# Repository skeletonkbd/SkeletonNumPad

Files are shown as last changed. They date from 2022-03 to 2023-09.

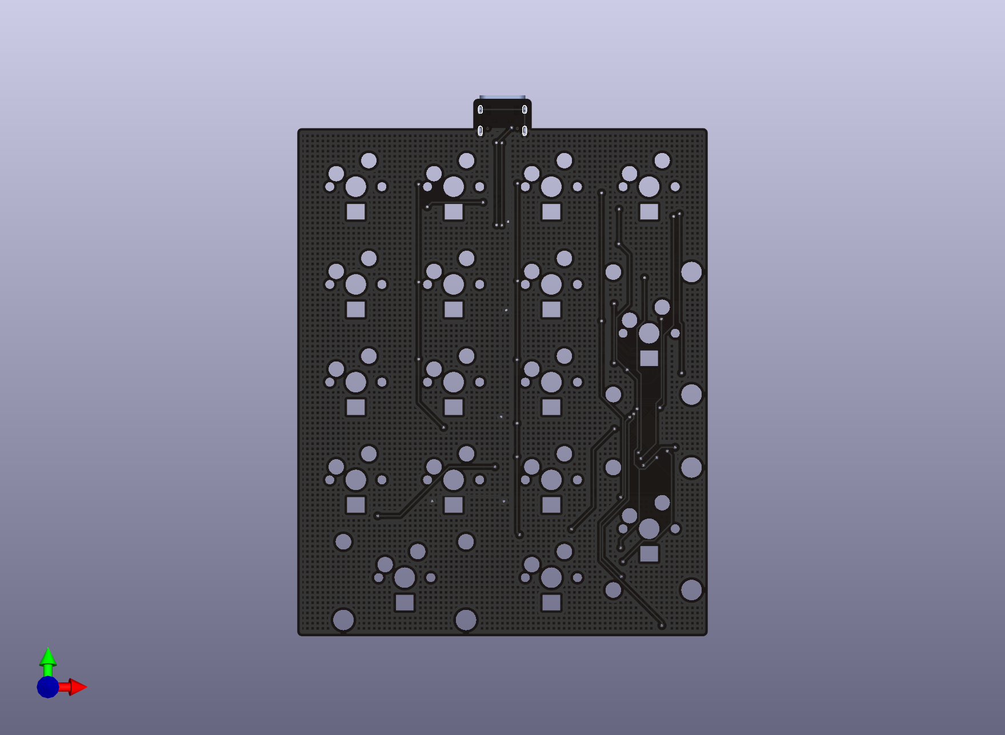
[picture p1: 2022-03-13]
3d/front.png

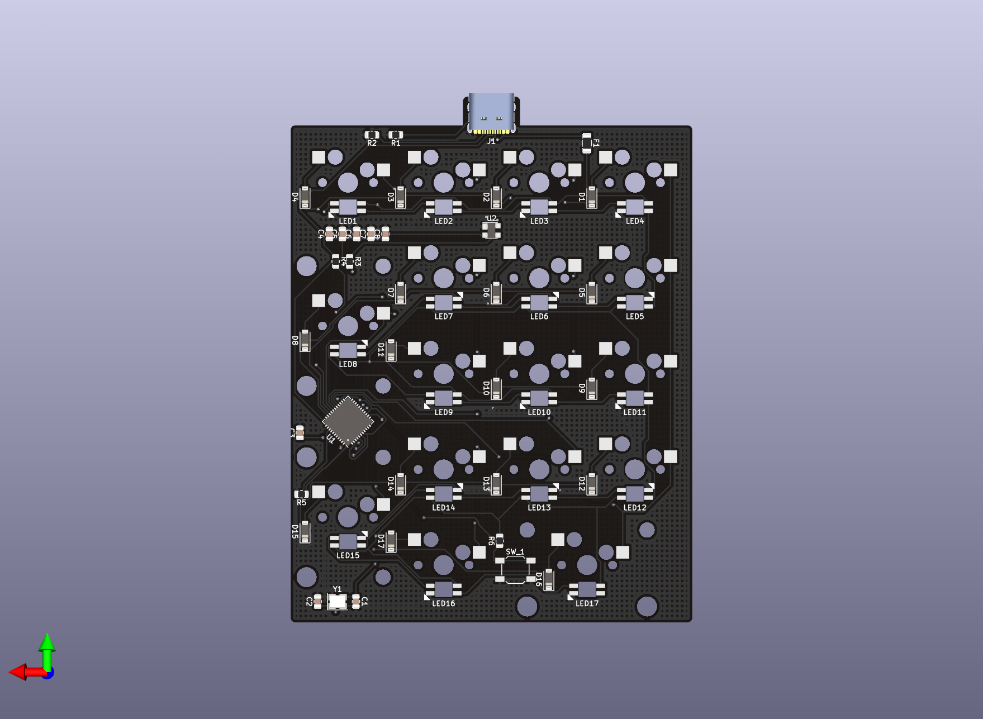
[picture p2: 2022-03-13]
3d/bottom.png

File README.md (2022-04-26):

# SkeletonNumPad

シンプルなNumpadです。販売ページは[こちら](https://skeletonkbd.com/products/numpad)。

## 特徴
- アクリル積層ケース
- バックライトLED
- ホットスワップ

# 組み立て例

skeletonNumPad

skeletonNumPad2

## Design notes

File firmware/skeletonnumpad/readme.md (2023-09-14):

# SkeletonNumPad

skeletonnumpad

Simple NumPad with acrylic case.

-   Keyboard Maintainer: [SkeletonKBD](https://github.com/skeletonkbd/SkeletonNumPad)
-   Hardware Supported: SkeletonNumPad
-   Hardware Availability: https://github.com/skeletonkbd/SkeletonNumPad

Make example for this keyboard (after setting up your build environment):

    make skeletonkbd/skeletonnumpad:default

Flashing example for this keyboard:

    make skeletonkbd/skeletonnumpad:default:flash

See the [build environment setup](https://docs.qmk.fm/#/getting_started_build_tools) and the [make instructions](https://docs.qmk.fm/#/getting_started_make_guide) for more information. Brand new to QMK? Start with our [Complete Newbs Guide](https://docs.qmk.fm/#/newbs).

## Bootloader

Enter the bootloader in 3 ways:

-   **Bootmagic reset**: Hold down the key at (0,0) in the matrix (usually the top left key or Escape) and plug in the keyboard
-   **Physical reset button**: Briefly press the button on the back of the PCB - some may have pads you must short instead
-   **Keycode in layout**: Press the key mapped to `QK_BOOT` if it is available

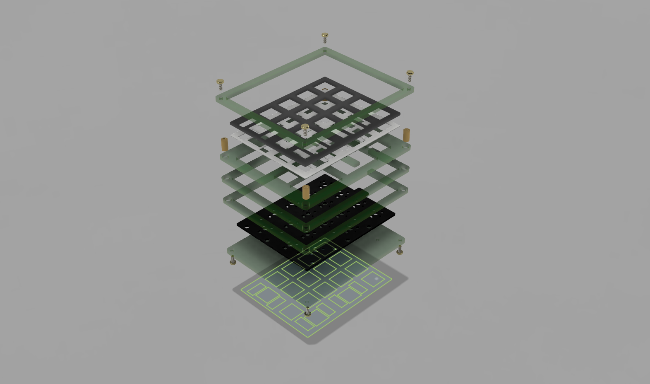
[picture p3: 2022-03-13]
3d/shape/SkeletonNumPad v3.png

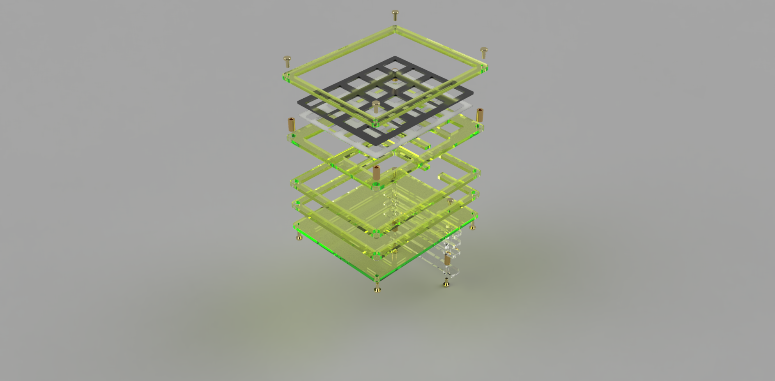
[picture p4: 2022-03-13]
3d/shape/331e11d3-f67b-4a33-b418-c3e450e3e0f4.PNG

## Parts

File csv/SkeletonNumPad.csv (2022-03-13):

Comment | Designator | Footprint | LCSC
22p | C1,C2 | Capacitor_SMD:C_0805_2012Metric | C1804
1u | C3 | Capacitor_SMD:C_0805_2012Metric | C28323
0.1u | C4,C5,C6,C7 | Capacitor_SMD:C_0805_2012Metric | C49678
10u | C8 | Capacitor_SMD:C_0805_2012Metric | C15850
D_Small | D1,D2,D3,D4,D5,D6,D7,D8,D9,D10,D11,D12,D13,D14,D15,D16,D17 | Diode_SMD:D_SOD-123 | C81598
500mA | F1 | Fuse:Fuse_1206_3216Metric | C70069
USB_C_Receptacle_USB2.0 | J1 | Connector_USB:USB_C_Receptacle_Palconn_UTC16-G | C167321
YS-SK6812MINI-E | LED1,LED2,LED3,LED4,LED5,LED6,LED7,LED8,LED9,LED10,LED11,LED12,LED13,LED14,LED15,LED16,LED17 | Custom:YS-SK6812MINI-E
5.1k | R1,R2 | Resistor_SMD:R_0805_2012Metric | C27834
22 | R3,R4 | Resistor_SMD:R_0805_2012Metric | C17561
10k | R5,R6 | Resistor_SMD:R_0805_2012Metric | C17414
SW_PUSH | SW1,SW2,SW3,SW4,SW5,SW6,SW7,SW9,SW10,SW11,SW12,SW13,SW14,SW17 | Custom:MXOnly-1U-Hotswap | C2803348
SW_PUSH | SW16 | Custom:MXOnly-2U-Hotswap | C2803348
SW_PUSH | SW8,SW15 | Custom:MXOnly-2U-Hotswap-VerticalStabilizers | C2803348
SW_PUSH | SW_1 | Button_Switch_SMD:SW_SPST_SKQG_WithStem | C455263
ATmega32U4-M | U1 | Package_DFN_QFN:QFN-44-1EP_7x7mm_P0.5mm_EP5.2x5.2mm | C112161
PRTR5V0U2X | U2 | Package_TO_SOT_SMD:SOT-143 | C2827688
Crystal_GND24 | Y1 | Crystal:Crystal_SMD_3225-4Pin_3.2x2.5mm | C13738

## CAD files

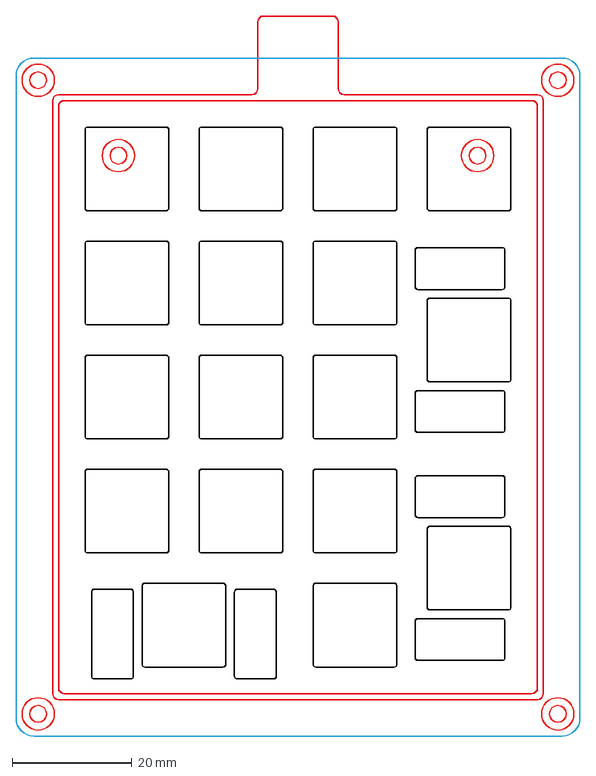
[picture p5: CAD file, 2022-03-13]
3d/shape/bottom.dxf
94.2 x 120.3 mm

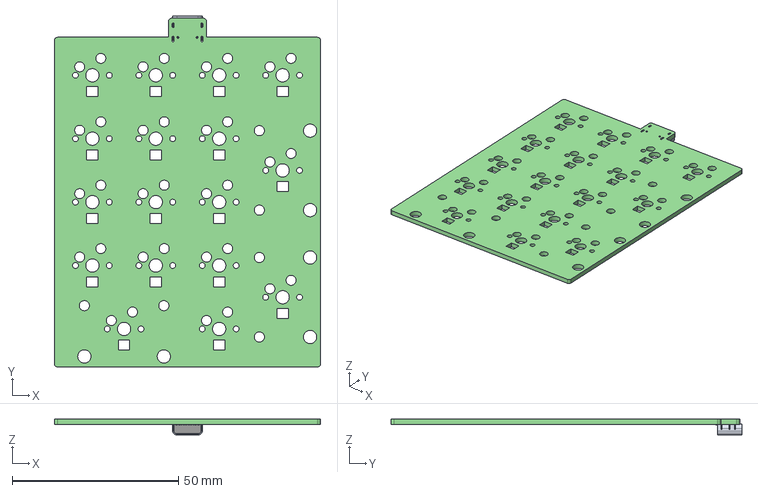
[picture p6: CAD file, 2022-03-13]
3d/SkeletonNumPad.step
80.0 x 105.4 x 4.76 mm
_autosave-SkeletonNumPad PCB

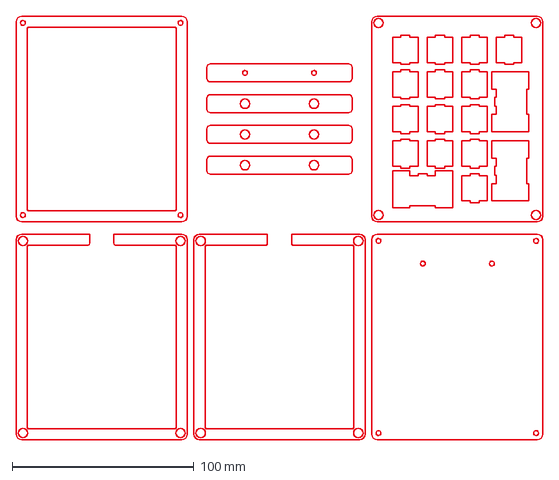
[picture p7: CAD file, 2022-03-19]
case/order-elecrow.dxf
290.0 x 233.3 mm

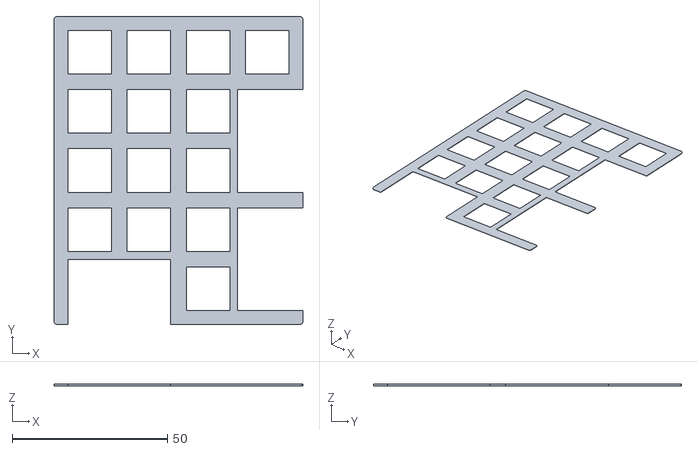
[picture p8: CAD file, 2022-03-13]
case/plate/dumper.stl
80.0 x 99.1 x 0.5

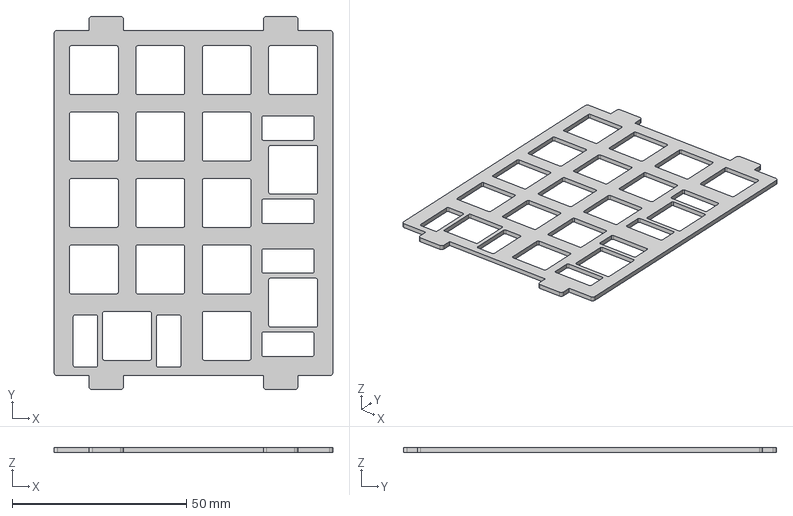
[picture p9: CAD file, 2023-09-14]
plate/SkeletonNumPad_plate.step
80.0 x 107.1 x 1.50 mm

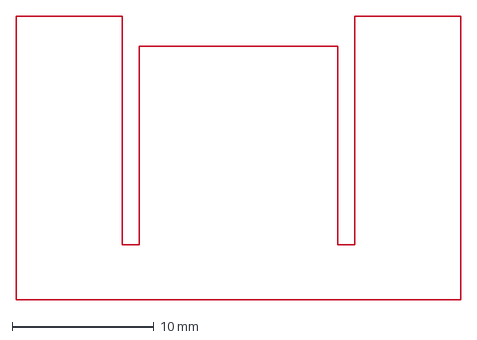
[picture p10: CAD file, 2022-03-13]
case/hole-sample.dxf
31.4 x 20.0 mm

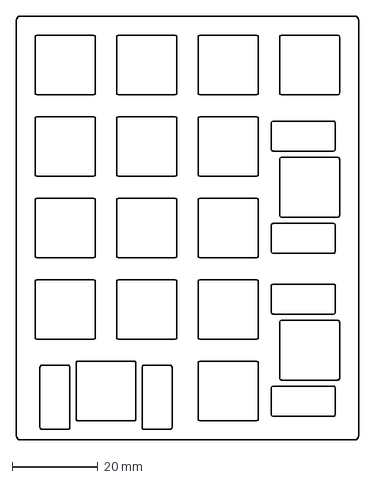
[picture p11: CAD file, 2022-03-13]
case/plate/switch-plate.dxf
80.0 x 99.1 mm

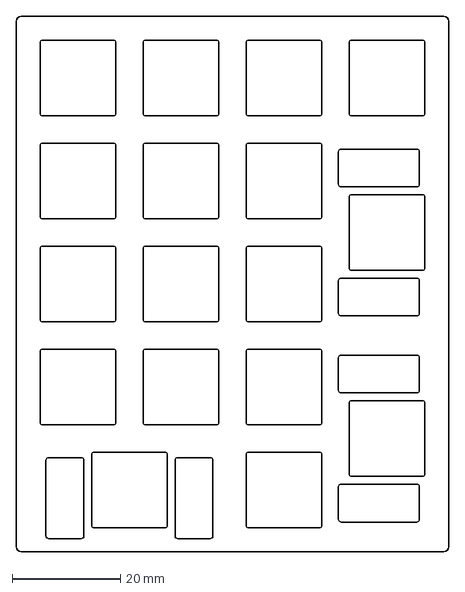
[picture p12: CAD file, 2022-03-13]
plate/switch-plate.dxf
80.0 x 99.1 mm

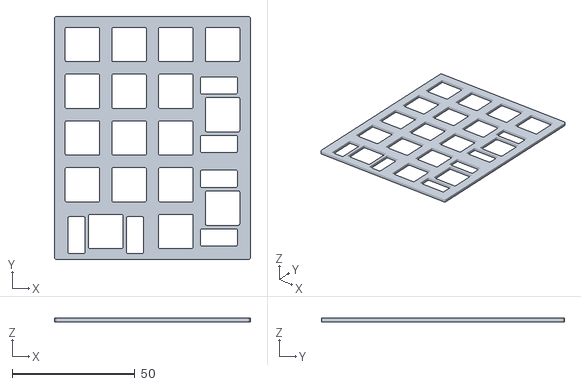
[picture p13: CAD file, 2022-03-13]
case/plate/switch-plate v1.stl
80.0 x 99.1 x 1.50

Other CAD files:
case/plate/dumper.dxf

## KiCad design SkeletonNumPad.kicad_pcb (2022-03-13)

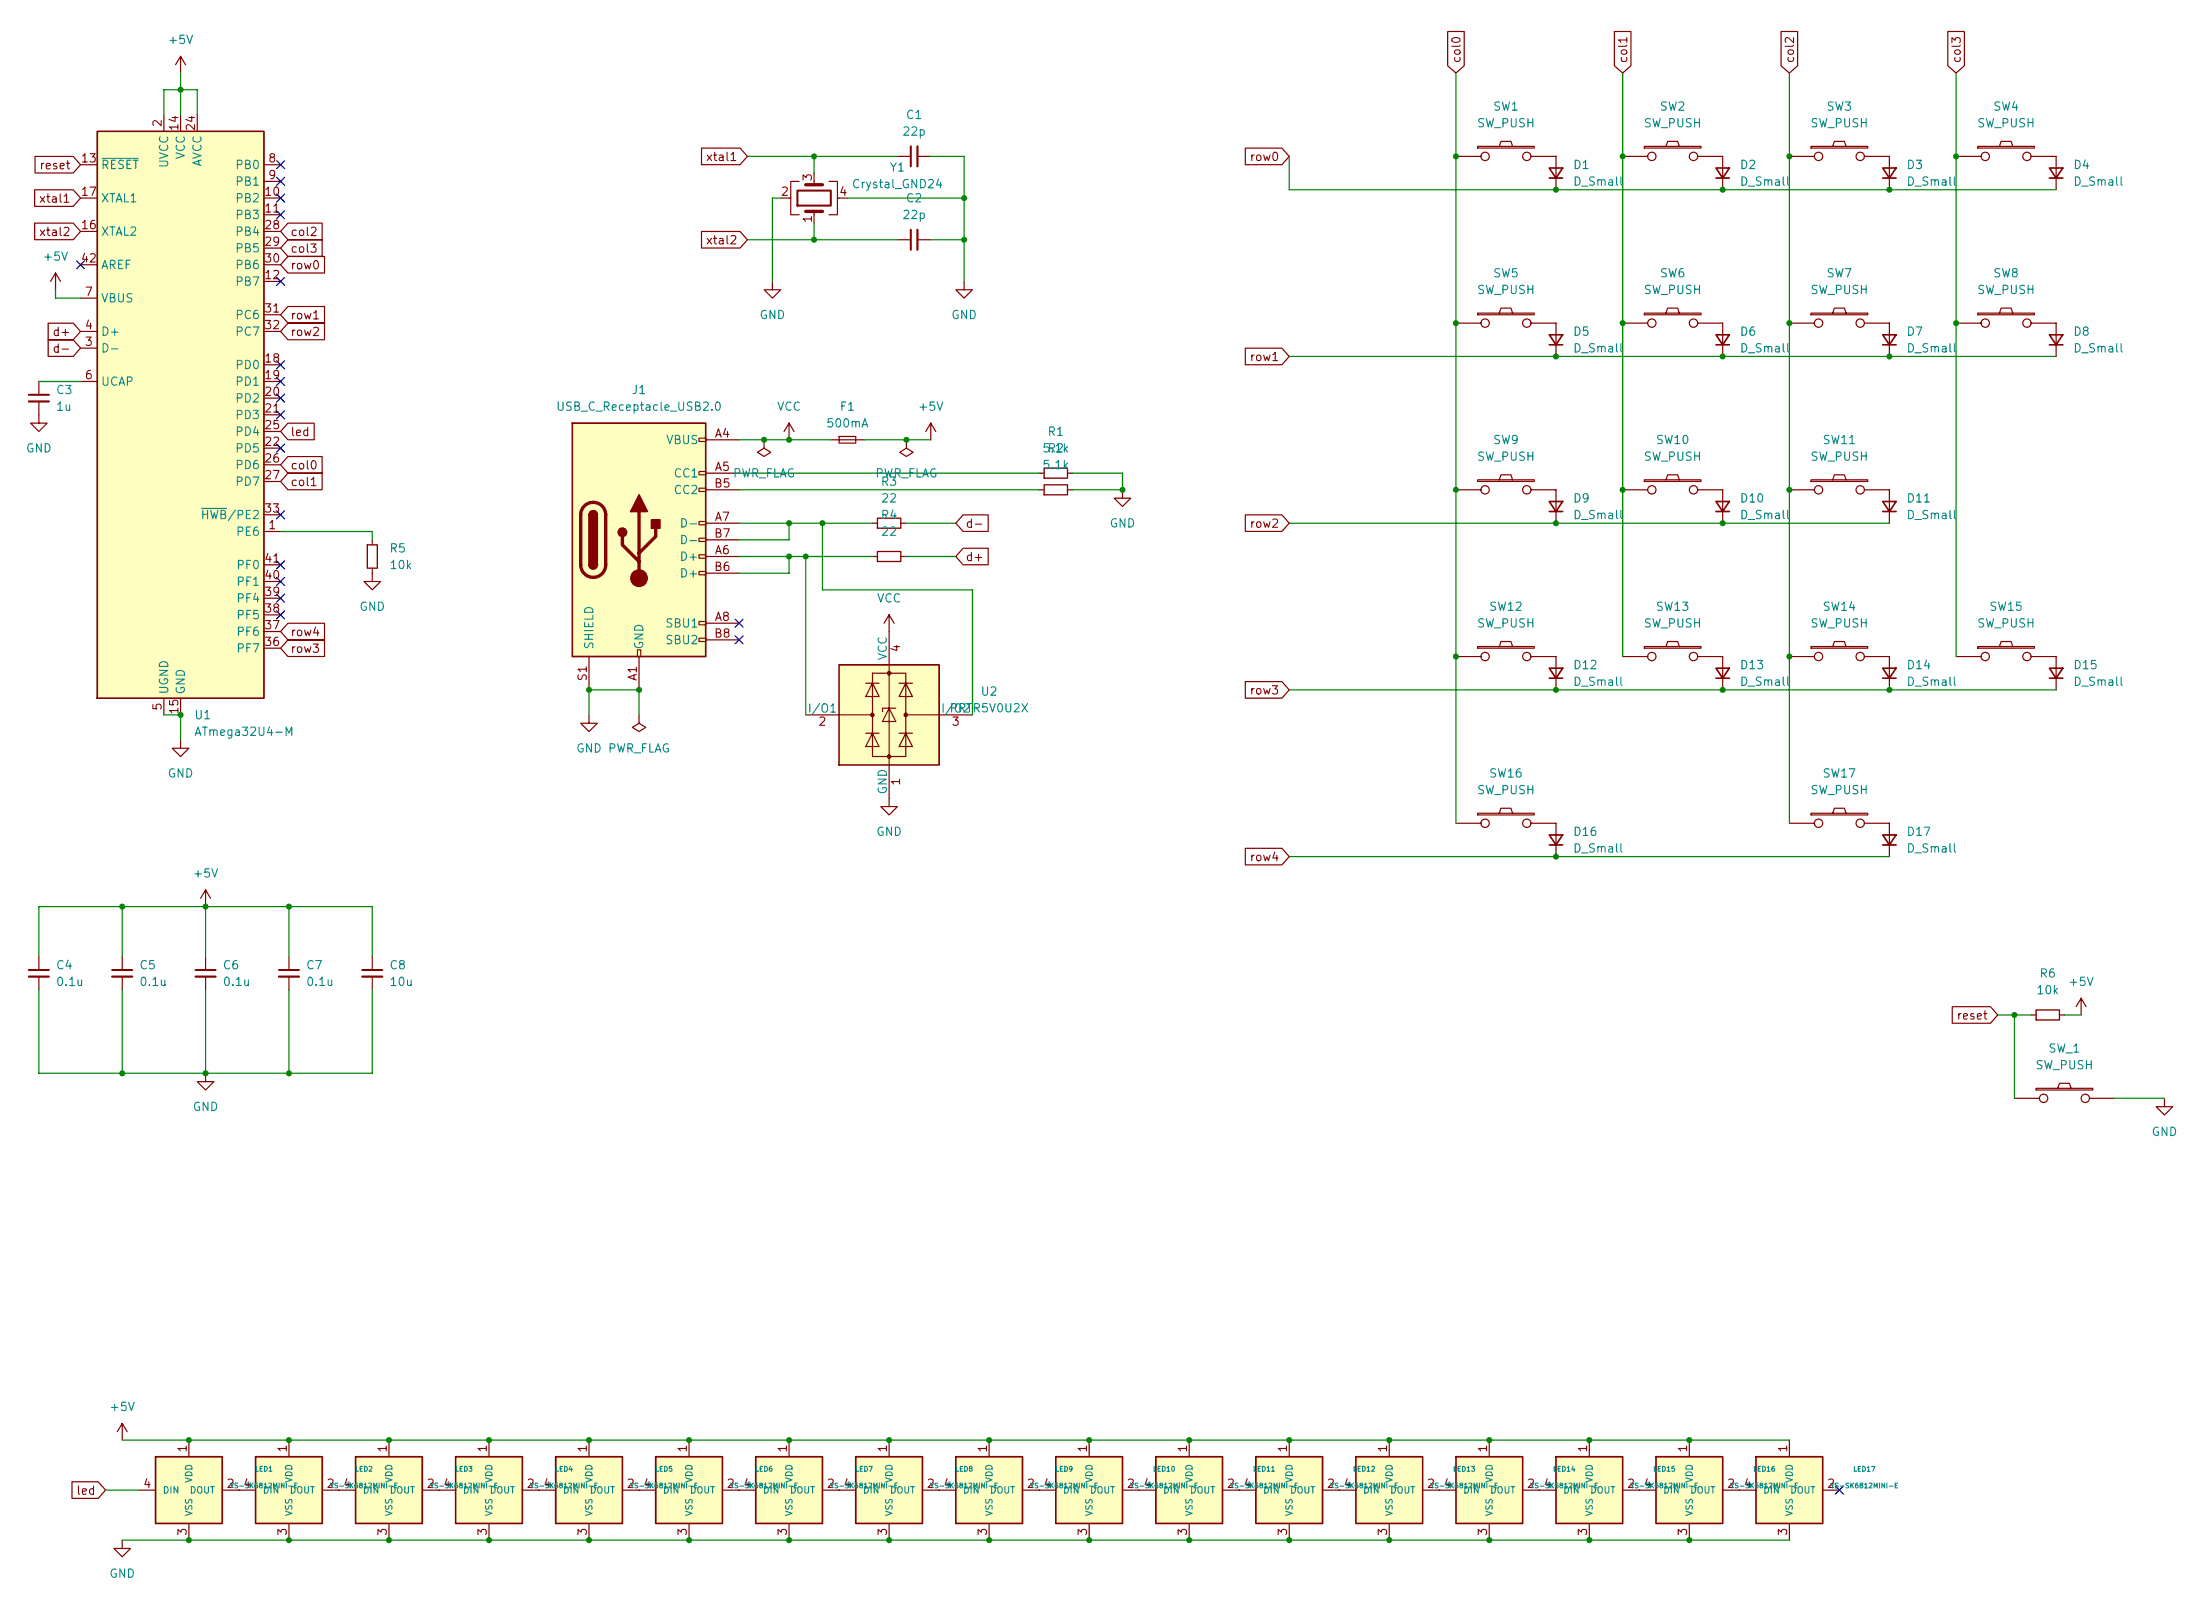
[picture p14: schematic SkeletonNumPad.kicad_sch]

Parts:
C1, C2: 22p; C_0805_2012Metric; LCSC C1804
C3: 1u; C_0805_2012Metric; LCSC C28323
C4, C5, C6, C7: 0.1u; C_0805_2012Metric; LCSC C49678
C8: 10u; C_0805_2012Metric; LCSC C15850
D1, D2, D3, D4, D5, D6, D7, D8, D9, D10, D11, D12, D13, D14, D15, D16, D17: D_Small; D_SOD-123; LCSC C81598
F1: 500mA; Fuse_1206_3216Metric; LCSC C70069
J1: USB_C_Receptacle_USB2.0; USB_C_Receptacle_Palconn_UTC16-G; LCSC C167321
LED1, LED2, LED3, LED4, LED5, LED6, LED7, LED8, LED9, LED10, LED11, LED12, LED13, LED14, LED15, LED16, LED17: YS-SK6812MINI-E
R1, R2: 5.1k; R_0805_2012Metric; LCSC C27834
R3, R4: 22; R_0805_2012Metric; LCSC C17561
R5, R6: 10k; R_0805_2012Metric; LCSC C17414
SW1, SW2, SW3, SW4, SW5, SW6, SW7, SW9, SW10, SW11, SW12, SW13, SW14, SW17: SW_PUSH; MXOnly-1U-Hotswap; LCSC C2803348
SW8, SW15: SW_PUSH; MXOnly-2U-Hotswap-VerticalStabilizers; LCSC C2803348
SW16: SW_PUSH; MXOnly-2U-Hotswap; LCSC C2803348
SW_1: SW_PUSH; SW_SPST_SKQG_WithStem; LCSC C455263
U1: ATmega32U4-M; QFN-44-1EP_7x7mm_P0.5mm_EP5.2x5.2mm; LCSC C112161
U2: PRTR5V0U2X; SOT-143; LCSC C2827688
Y1: Crystal_GND24; Crystal_SMD_3225-4Pin_3.2x2.5mm; LCSC C13738

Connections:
+5V: C4.1, C5.1, C6.1, C7.1, C8.1, F1.2, LED1.1 (VDD), LED2.1 (VDD), LED3.1 (VDD), LED4.1 (VDD), LED5.1 (VDD), LED6.1 (VDD), LED7.1 (VDD), LED8.1 (VDD), LED9.1 (VDD), LED10.1 (VDD), LED11.1 (VDD), LED12.1 (VDD), LED13.1 (VDD), LED14.1 (VDD), LED15.1 (VDD), LED16.1 (VDD), LED17.1 (VDD), R6.2, U1.2 (UVCC), U1.7 (VBUS), U1.14 (VCC), U1.24 (AVCC), U1.34 (VCC), U1.44 (AVCC)
GND: C1.2, C2.2, C3.2, C4.2, C5.2, C6.2, C7.2, C8.2, J1.A1 (GND), J1.A12 (GND), J1.B1 (GND), J1.B12 (GND), J1.S1 (SHIELD), LED1.3 (VSS), LED2.3 (VSS), LED3.3 (VSS), LED4.3 (VSS), LED5.3 (VSS), LED6.3 (VSS), LED7.3 (VSS), LED8.3 (VSS), LED9.3 (VSS), LED10.3 (VSS), LED11.3 (VSS), LED12.3 (VSS), LED13.3 (VSS), LED14.3 (VSS), LED15.3 (VSS), LED16.3 (VSS), LED17.3 (VSS), R1.2, R2.2, R5.2, SW_1.2, U1.5 (UGND), U1.15 (GND), U1.23 (GND), U1.35 (GND), U1.43 (GND), U1.45 (GND), U2.1 (GND), Y1.2, Y1.4
unnamed: C3.1, U1.6 (UCAP)
unnamed: D1.2 (A), SW1.2
unnamed: D2.2 (A), SW2.2
unnamed: D3.2 (A), SW3.2
unnamed: D4.2 (A), SW4.2
unnamed: D5.2 (A), SW5.2
unnamed: D6.2 (A), SW6.2
unnamed: D7.2 (A), SW7.2
unnamed: D8.2 (A), SW8.2
unnamed: D9.2 (A), SW9.2
unnamed: D10.2 (A), SW10.2
unnamed: D11.2 (A), SW11.2
unnamed: D12.2 (A), SW12.2
unnamed: D13.2 (A), SW13.2
unnamed: D14.2 (A), SW14.2
unnamed: D15.2 (A), SW15.2
unnamed: D16.2 (A), SW16.2
unnamed: D17.2 (A), SW17.2
unnamed: J1.A5 (CC1), R1.1
unnamed: J1.A6 (D+), J1.B6 (D+), R4.1, U2.2 (I/O1)
unnamed: J1.A7 (D-), J1.B7 (D-), R3.1, U2.3 (I/O2)
unnamed: J1.B5 (CC2), R2.1
unnamed: LED1.2 (DOUT), LED2.4 (DIN)
unnamed: LED2.2 (DOUT), LED3.4 (DIN)
unnamed: LED3.2 (DOUT), LED4.4 (DIN)
unnamed: LED4.2 (DOUT), LED5.4 (DIN)
unnamed: LED5.2 (DOUT), LED6.4 (DIN)
unnamed: LED6.2 (DOUT), LED7.4 (DIN)
unnamed: LED7.2 (DOUT), LED8.4 (DIN)
unnamed: LED8.2 (DOUT), LED9.4 (DIN)
unnamed: LED10.2 (DOUT), LED11.4 (DIN)
unnamed: LED9.2 (DOUT), LED10.4 (DIN)
unnamed: LED11.2 (DOUT), LED12.4 (DIN)
unnamed: LED12.2 (DOUT), LED13.4 (DIN)
unnamed: LED13.2 (DOUT), LED14.4 (DIN)
unnamed: LED14.2 (DOUT), LED15.4 (DIN)
unnamed: LED15.2 (DOUT), LED16.4 (DIN)
unnamed: LED16.2 (DOUT), LED17.4 (DIN)
unnamed: R5.1, U1.1 (PE6)
VCC: F1.1, J1.A4 (VBUS), J1.A9 (VBUS), J1.B4 (VBUS), J1.B9 (VBUS), U2.4 (VCC)
col0: SW1.1, SW5.1, SW9.1, SW12.1, SW16.1, U1.26 (PD6)
col1: SW2.1, SW6.1, SW10.1, SW13.1, U1.27 (PD7)
col2: SW3.1, SW7.1, SW11.1, SW14.1, SW17.1, U1.28 (PB4)
col3: SW4.1, SW8.1, SW15.1, U1.29 (PB5)
d+: R4.2, U1.4 (D+)
d-: R3.2, U1.3 (D-)
led: LED1.4 (DIN), U1.25 (PD4)
reset: R6.1, SW_1.1, U1.13 (~RESET)
row0: D1.1 (K), D2.1 (K), D3.1 (K), D4.1 (K), U1.30 (PB6)
row1: D5.1 (K), D6.1 (K), D7.1 (K), D8.1 (K), U1.31 (PC6)
row2: D9.1 (K), D10.1 (K), D11.1 (K), U1.32 (PC7)
row3: D12.1 (K), D13.1 (K), D14.1 (K), D15.1 (K), U1.36 (PF7)
row4: D16.1 (K), D17.1 (K), U1.37 (PF6)
xtal1: C1.1, U1.17 (XTAL1), Y1.3
xtal2: C2.1, U1.16 (XTAL2), Y1.1

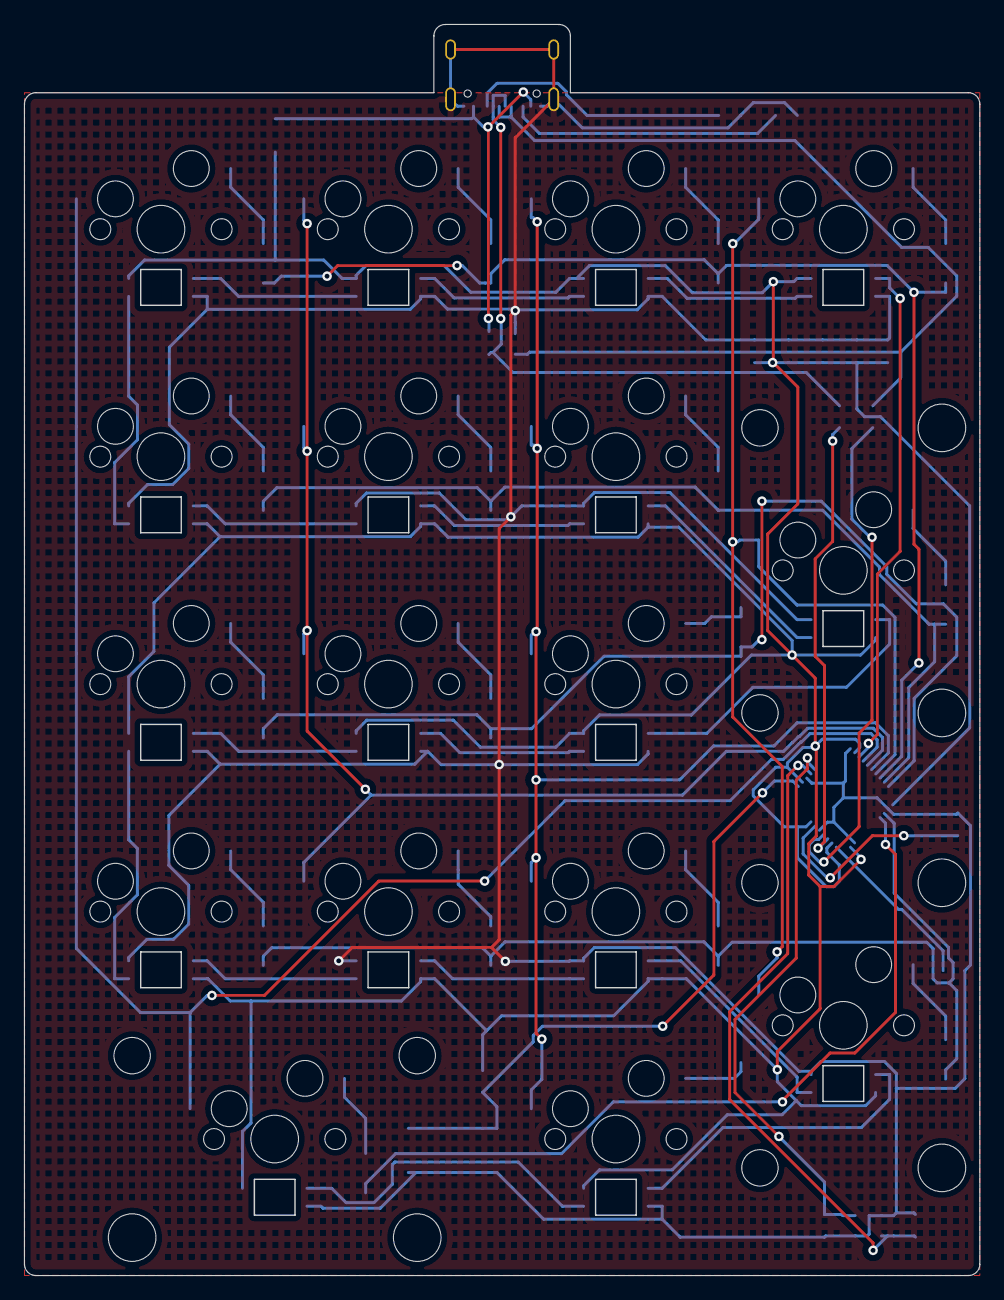
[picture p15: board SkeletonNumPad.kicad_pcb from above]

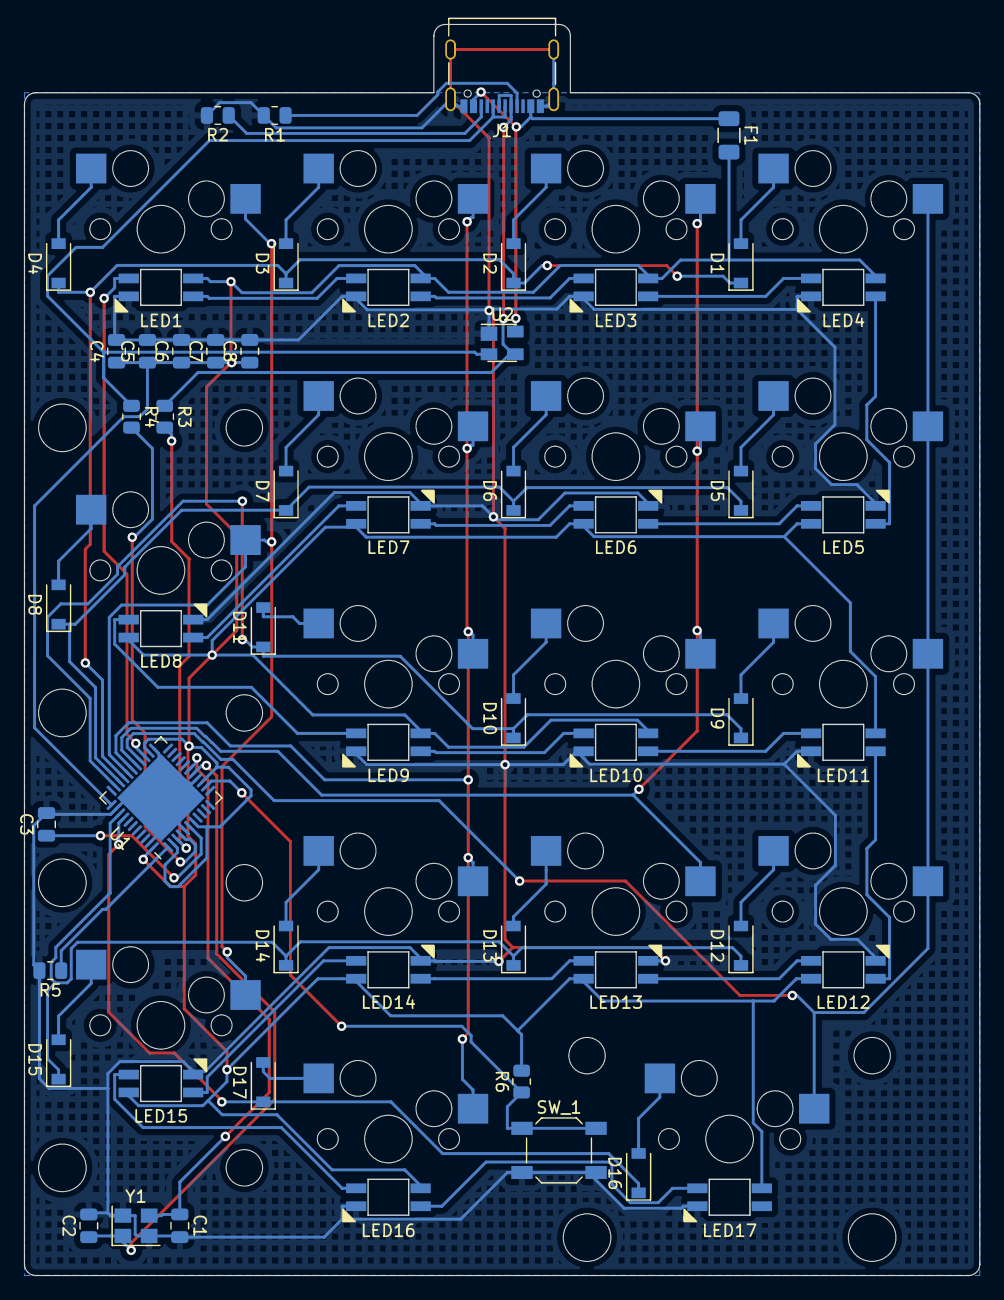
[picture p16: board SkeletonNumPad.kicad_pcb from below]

Board: 2 copper layers, 80.0 x 104.8 mm, 71 parts (71 on the bottom side), 57 nets.

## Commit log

2022-01-18 Customize footprints
    [SkeletonNumPad.kicad_pcb, SkeletonNumPad.kicad_sch]
2022-02-21 with WS2812B-2020
    [SkeletonNumPad-B_Cu.gbl, SkeletonNumPad-B_Cu.gbr, SkeletonNumPad-B_Mask.gbr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]
2022-02-21 with SK6812mini-e
    [SkeletonNumPad.dsn, SkeletonNumPad.kicad_pcb, SkeletonNumPad.kicad_sch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]
2022-03-19 case v2
    [5mmスタビライザー検証 v1.stl, order-elecrow.dxf]
2023-09-14 add firmware
    [SkeletonNumPad_plate.step]
